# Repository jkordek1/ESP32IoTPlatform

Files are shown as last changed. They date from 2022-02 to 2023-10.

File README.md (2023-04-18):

# ESP32IoTPlatform


[]()



## What is it?
ESP32IoTPlatform is an open source platform aimed towards students at Zagreb University of Applied Sciences who will take the IoT course.
It enables quick and easy firmware development thanks to built in sensors, actuators and other electronic components.

## Features
- Based on dual-core ESP32 microcontroller module
- External battery connector
- Battery charging via microUSB cable
- Buzzer for audio queues
- HC-SR04 ultrasonic sensor connector
- MOSFET output
- Relay output
- LDR
- Potentiometer
- 1.3" OLED screen
- microSD slot
- accelerometer & gyro
- BME280 temperature and humidity sensor
- GPS module
- WS2812-B RGB LEDs
- Touchad
- Joypad

## Images
<p align="center">
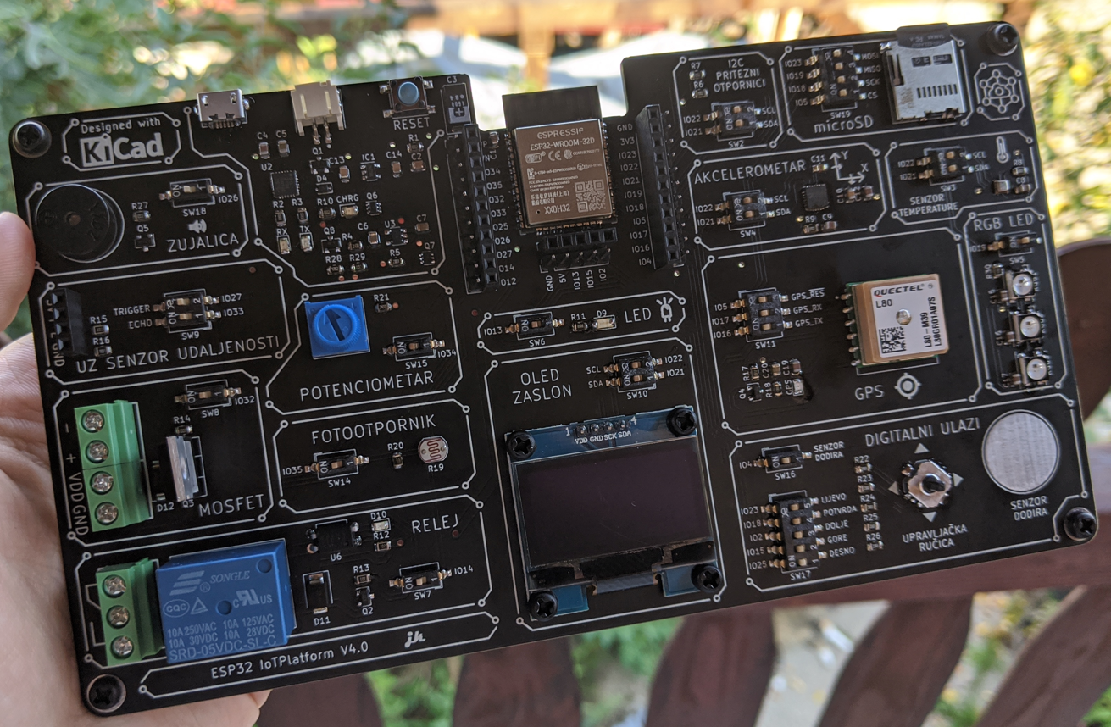
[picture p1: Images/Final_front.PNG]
 
</p>

## Project folder structure
    .
    ├── ...
    ├── Images                  # Images of the project
    ├── Output files            # Gerber files
    ├── KiCadFiles              # Main folder
    │   ├── 3d modeli           # 3D models of added components
    │   ├── Board2Pdf           # Assembly files
    │   ├── bom                 # ibom assembly files
    │   └── gerber              # gerber
    ├── Schematic.pdf           # Schematic .pdf file
    └── ...

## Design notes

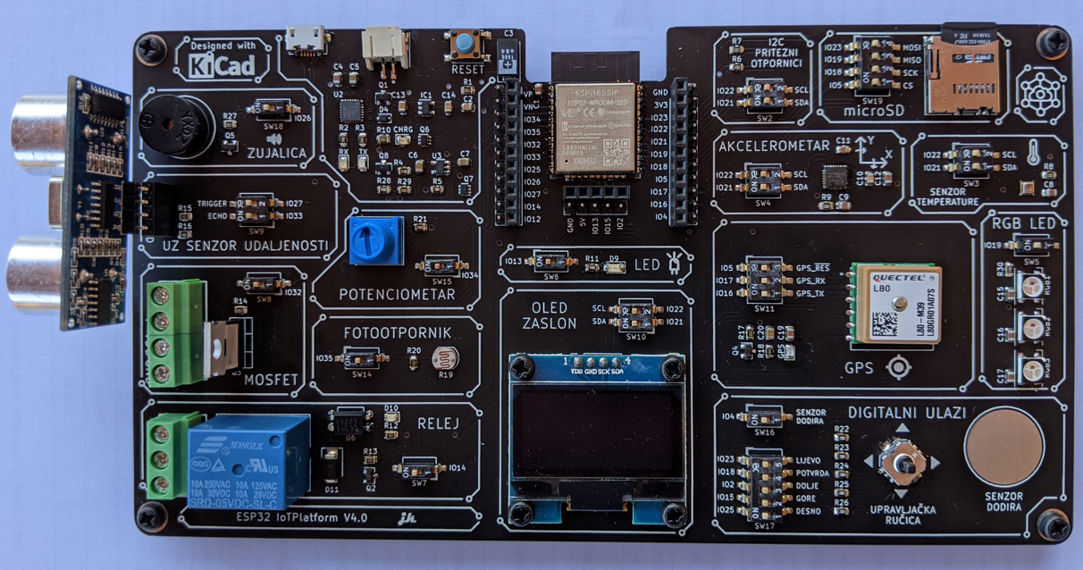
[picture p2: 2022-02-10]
Images/Front_2.PNG

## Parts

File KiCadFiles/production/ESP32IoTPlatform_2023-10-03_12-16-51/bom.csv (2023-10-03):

Designator | Footprint | Quantity | Value | LCSC Part #
BZ1 | PS1240P02BT | 1 | Buzzer
C1, C12, C15, C16, C17, C19, C4, C8, C9 | 0805 | 9 | 100n/50V
C10 | 0805 | 1 | 10n/6.3V
C11 | 0805 | 1 | 2200p/50V
C13, C14, C2 | 0805 | 3 | 1u/50V
C20, C5, C6, C7 | 0805 | 4 | 10u/16V
C3 | CP_EIA-7343-31_Kemet-D | 1 | 1500u
D1, D13 | 0805 | 2 | Green
D10, D2 | 0805 | 2 | Red
D11, D12 | D_SMA | 2 | S1BB-13-F
D3 | 0805 | 1 | Orange
D4 | D_SOD-323 | 1 | B5819WS
D5, D6, D7 | LED_WS2812B_PLCC4_5.0x5.0mm_P3.2mm | 3 | WS2812B
D9 | 1206 | 1 | Blue
H1, H2, H3, H4 | MountingHole_3.2mm_M3_Pad_Via_edited | 4 | MountingHole
IC1 | SOT-23-5 | 1 | ME6211C33M5G
J1 | USB_Micro-AB_Molex_47590-0001 | 1 | USB_B_Micro
J10, J9 | PinSocket_1x11_P2.54mm_Vertical | 2 | Conn_01x11_Female
J11, J12 | PinHeader_1x11_P2.54mm_Vertical | 2 | Conn_01x11_Male
J2 | TerminalBlock_Phoenix_MKDS-1,5-3-5.08_1x03_P5.08mm_Horizontal | 1 | Screw_Terminal_01x03
J3, J4 | TerminalBlock_Phoenix_MKDS-1,5-2-5.08_1x02_P5.08mm_Horizontal | 2 | Screw_Terminal_01x02
J5 | PinSocket_1x04_P2.54mm_Vertical | 1 | Conn_01x04_Female
J6 | OLED | 1 | OLED
J7 | PinSocket_1x05_P2.54mm_Vertical | 1 | Conn_01x05_Female
J8 | PinHeader_1x05_P2.54mm_Vertical | 1 | Conn_01x05_Male
JST1 | A2001WR-S-2P_JST2.0 | 1 | JST2.0
K1 | Relay_SPDT_SANYOU_SRD_Series_Form_C | 1 | SANYOU_SRD_Form_C
Q1, Q8 | SOT-23 | 2 | CJ2301
Q2 | SOT-23 | 1 | S8050G
Q3 | TO-220-3_Vertical | 1 | IRLZ44N
Q4, Q5 | SOT-23 | 2 | SI2302DS
Q6 | SOT-363_SC-70-6 | 1 | Q_DUAL_NPN_UMH3N
Q7 | SOT-363_SC-70-6 | 1 | Q_DUAL_PNP_BCM857BS
R1, R10, R14, R17, R20, R27, R29, R6, R7, R8, R9 | 0805 | 11 | 10k
R11, R2, R3, R31, R32 | 0805 | 5 | 330
R12, R13, R15 | 0805 | 3 | 1k
R16 | 0805 | 1 | 1k5
R18, R30 | 0805 | 2 | 470
R19 | R_LDR_7x6mm_P5.1mm_Vertical | 1 | LDR
R21, R4 | 0805 | 2 | 243
R22, R23, R24, R25, R26, R5 | 0805 | 6 | 2k
R28 | 0805 | 1 | 47k
RV1 | Potentiometer_Bourns_3386P_Vertical | 1 | 10k
SD1 | MOLEX_47352-1001 | 1 | microSD-MOLEX-473521001
SW1 | SW_SPST_PTS645 | 1 | SW_Push
SW10, SW2, SW3, SW4, SW9 | SW_DIP_SPSTx02_Slide_6.7x6.64mm_W6.73mm_P2.54mm_LowProfile_JPin | 5 | SW_x02
SW11 | SW_DIP_SPSTx03_Slide_6.7x9.18mm_W6.73mm_P2.54mm_LowProfile_JPin | 1 | SW_x03
SW14, SW15, SW16, SW18, SW5, SW6, SW7, SW8 | SW_DIP_SPSTx01_Slide_6.7x4.1mm_W6.73mm_P2.54mm_LowProfile_JPin | 8 | SW_x01
SW17 | SW_DIP_SPSTx05_Slide_6.7x14.26mm_W6.73mm_P2.54mm_LowProfile_JPin | 1 | SW_x05
SW19 | SW_DIP_SPSTx04_Slide_6.7x11.72mm_W6.73mm_P2.54mm_LowProfile_JPin | 1 | SW_x04
T1 | Alps_SKRHABE010 | 1 | SKRHABE010
TP1 | Touchpad | 1 | Touchpad
U1 | ESP32-WROOM-32 | 1 | ESP32-WROOM-32D
U2 | QFN-24-1EP_4x4mm_P0.5mm_EP2.6x2.6mm | 1 | CP2104
U3 | TSOT-23-5 | 1 | TP4054
U4 | Bosch_LGA-8_2.5x2.5mm_P0.65mm_ClockwisePinNumbering | 1 | BME280
U5 | InvenSense_QFN-24_4x4mm_P0.5mm | 1 | MPU-6050
U6 | DIP-4_W7.62mm | 1 | PC817
U7 | L80-M39 | 1 | L80-M39

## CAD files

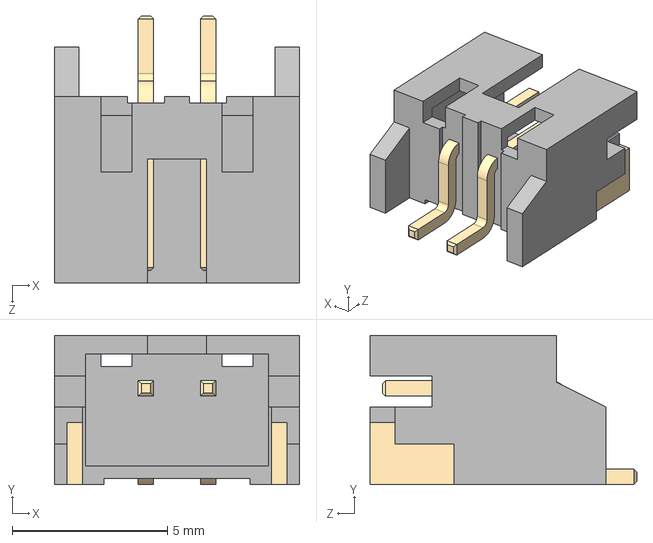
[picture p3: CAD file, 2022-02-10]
KiCadFiles/3d modeli/S2B-PH-SM4-TB.STEP
7.90 x 4.80 x 8.60 mm

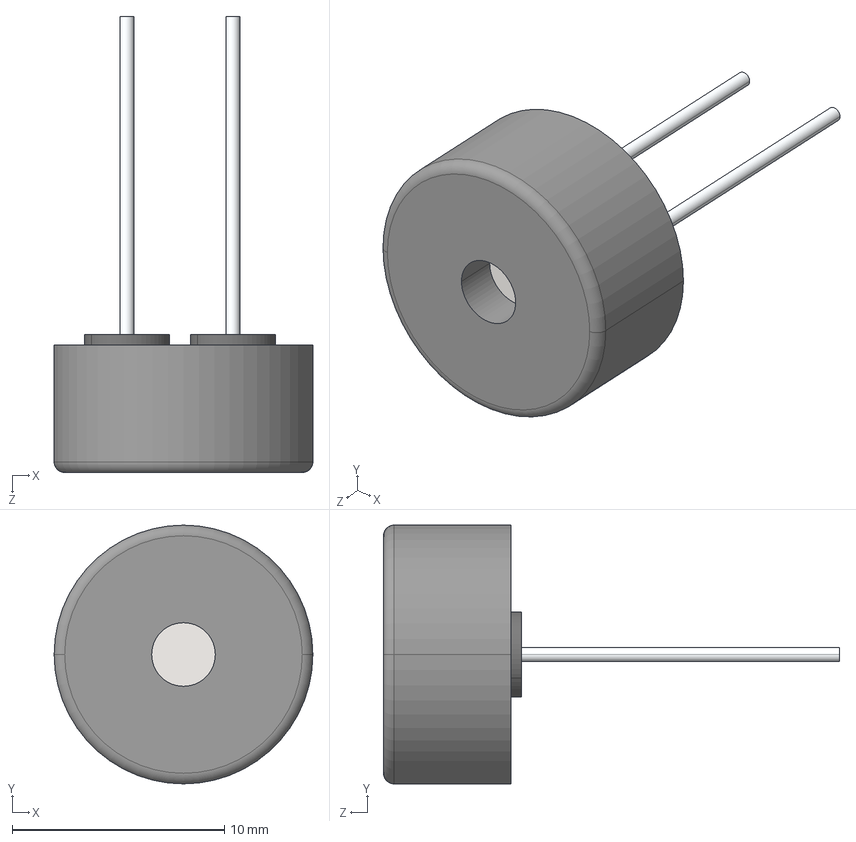
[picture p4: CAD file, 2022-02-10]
KiCadFiles/3d modeli/PS1240P02BT.step
12.2 x 12.2 x 21.5 mm
leg x 2
legbase x 2

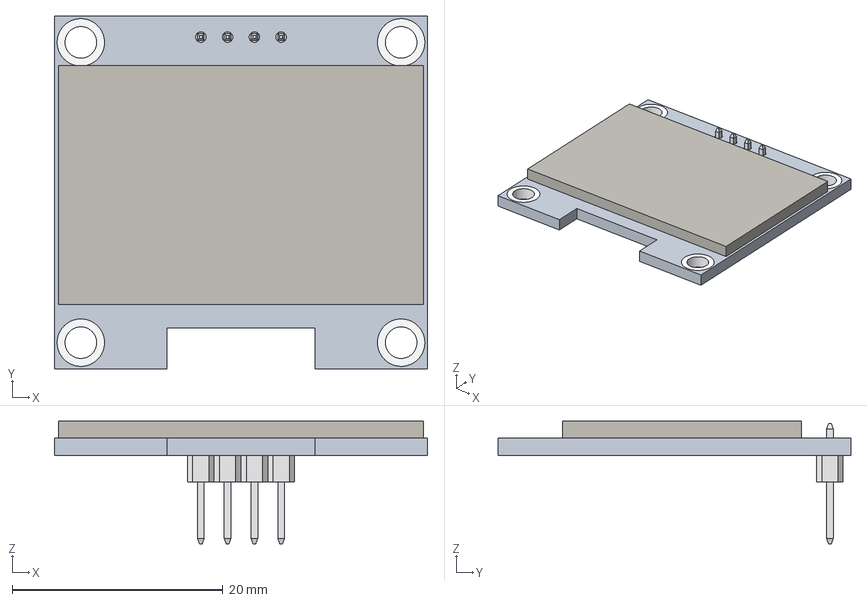
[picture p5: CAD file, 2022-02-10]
KiCadFiles/3d modeli/Geekcreit 1.3 Inch 4Pin.step
35.4 x 33.5 x 11.6 mm
2.54mm_pin_header x 4

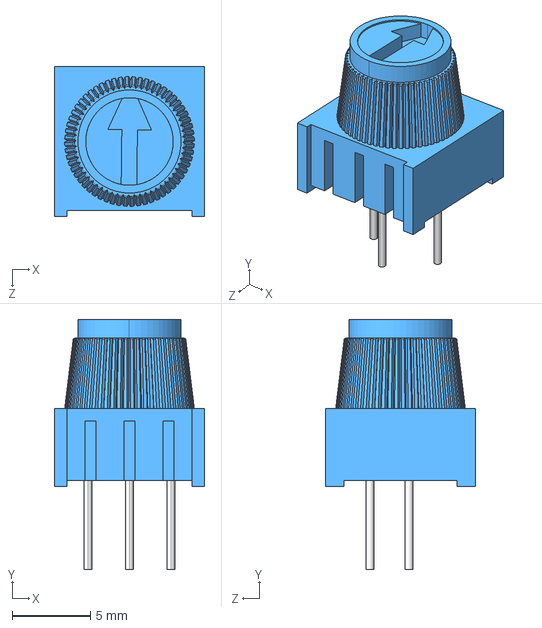
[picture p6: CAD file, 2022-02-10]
KiCadFiles/3d modeli/10 KILO-OHM BREADBOARD TRIM POTENTIOMETER WITH KNOB.STEP
9.60 x 16.0 x 9.60 mm
BASE, 10 KILO-OHM BREADBOARD TRIM POTENTIOMETER WITH KNOB
KNOB, 10 KILO-OHM BREADBOARD TRIM POTENTIOMETER WITH KNOB

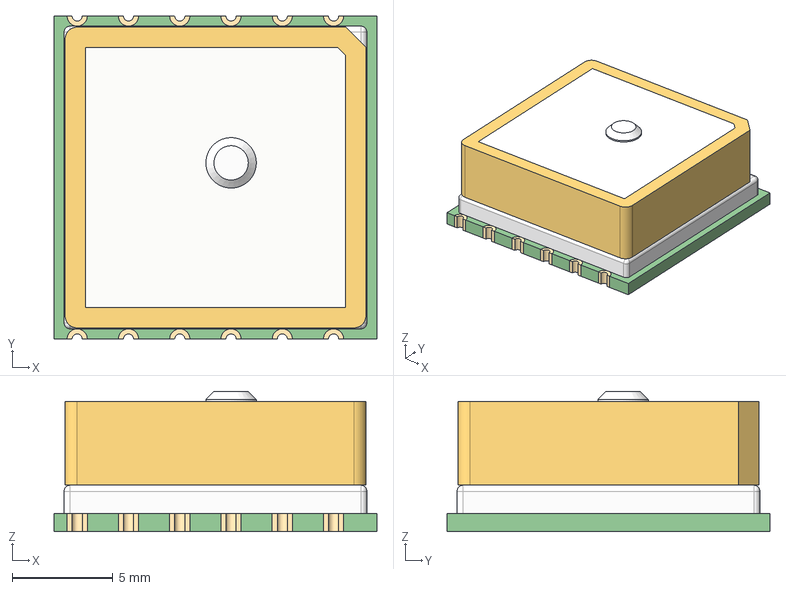
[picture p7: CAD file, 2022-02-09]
KiCadFiles/3d modeli/Quectel L80.step
16.0 x 16.0 x 6.95 mm

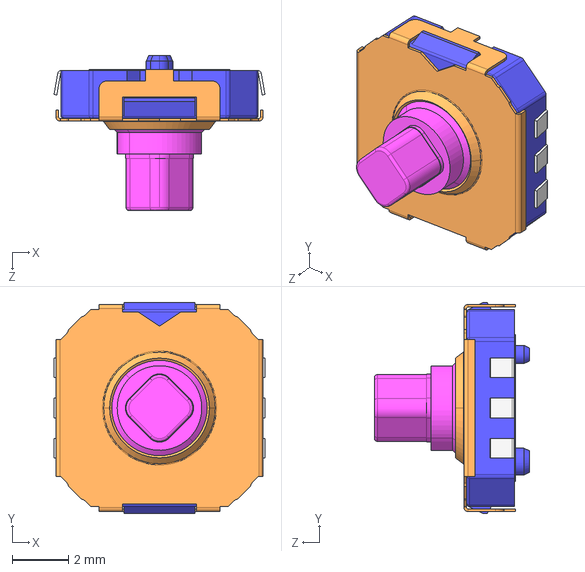
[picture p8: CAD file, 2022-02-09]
KiCadFiles/3d modeli/SKRHAB.STEP
7.48 x 7.50 x 5.50 mm

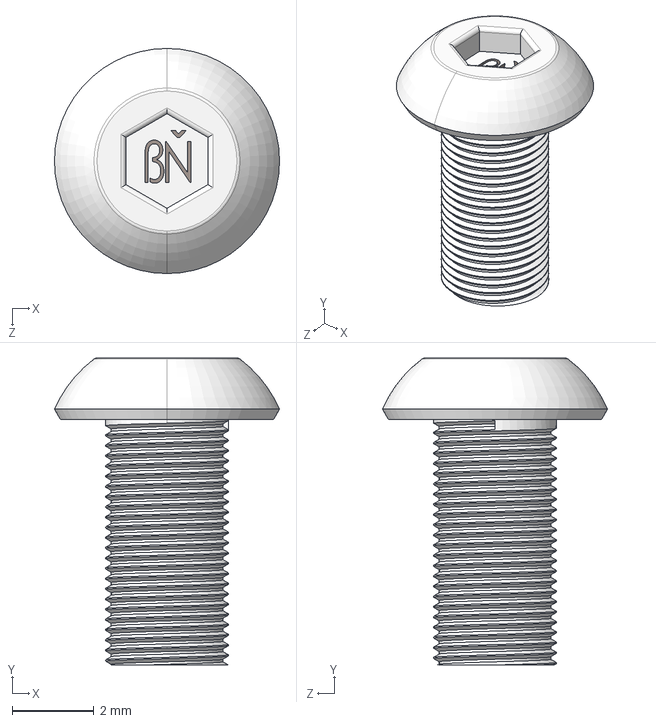
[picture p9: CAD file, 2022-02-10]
KiCadFiles/3d modeli/Screw_Machine_M3x6.STEP
5.50 x 7.50 x 5.50 mm

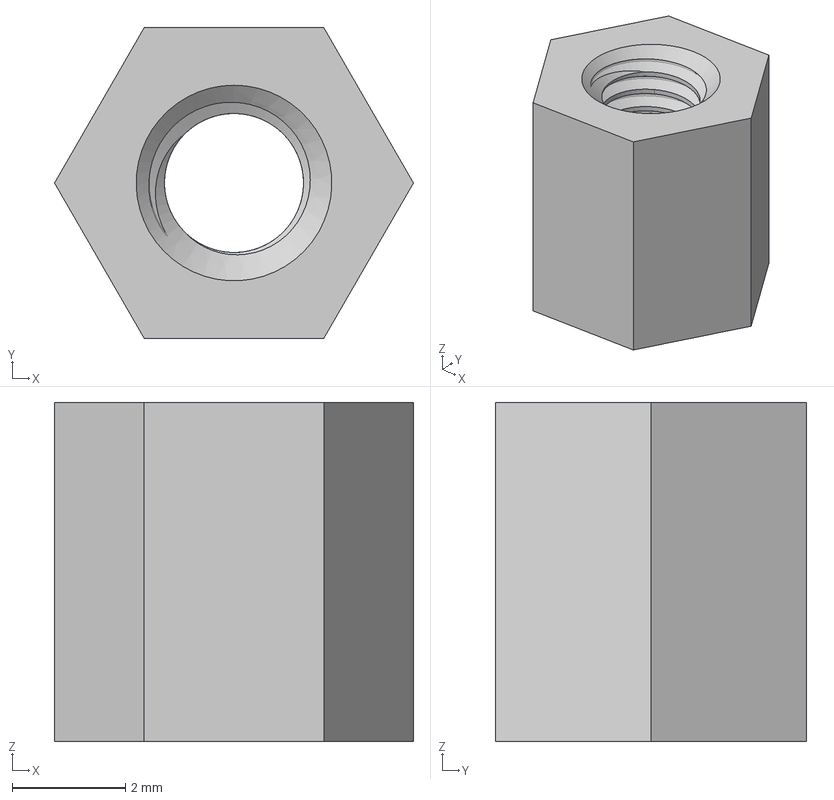
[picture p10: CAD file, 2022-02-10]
KiCadFiles/3d modeli/hex spacer standoff nut_M3 L6.stp
6.35 x 5.50 x 6.00 mm

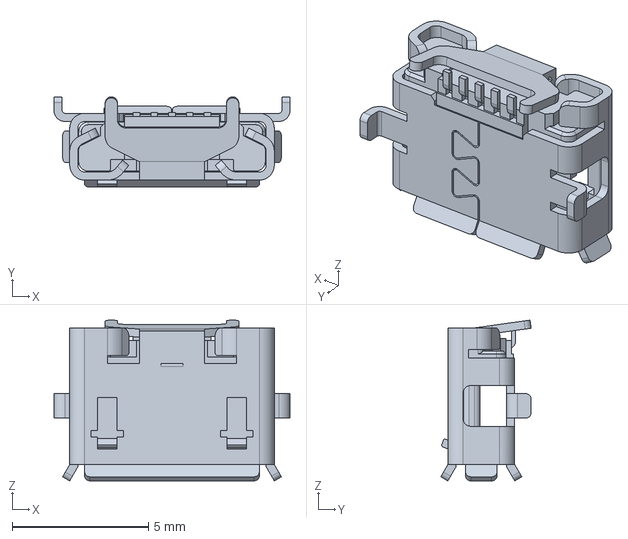
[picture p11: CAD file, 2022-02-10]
KiCadFiles/3d modeli/475890001.stp
8.65 x 3.31 x 5.89 mm

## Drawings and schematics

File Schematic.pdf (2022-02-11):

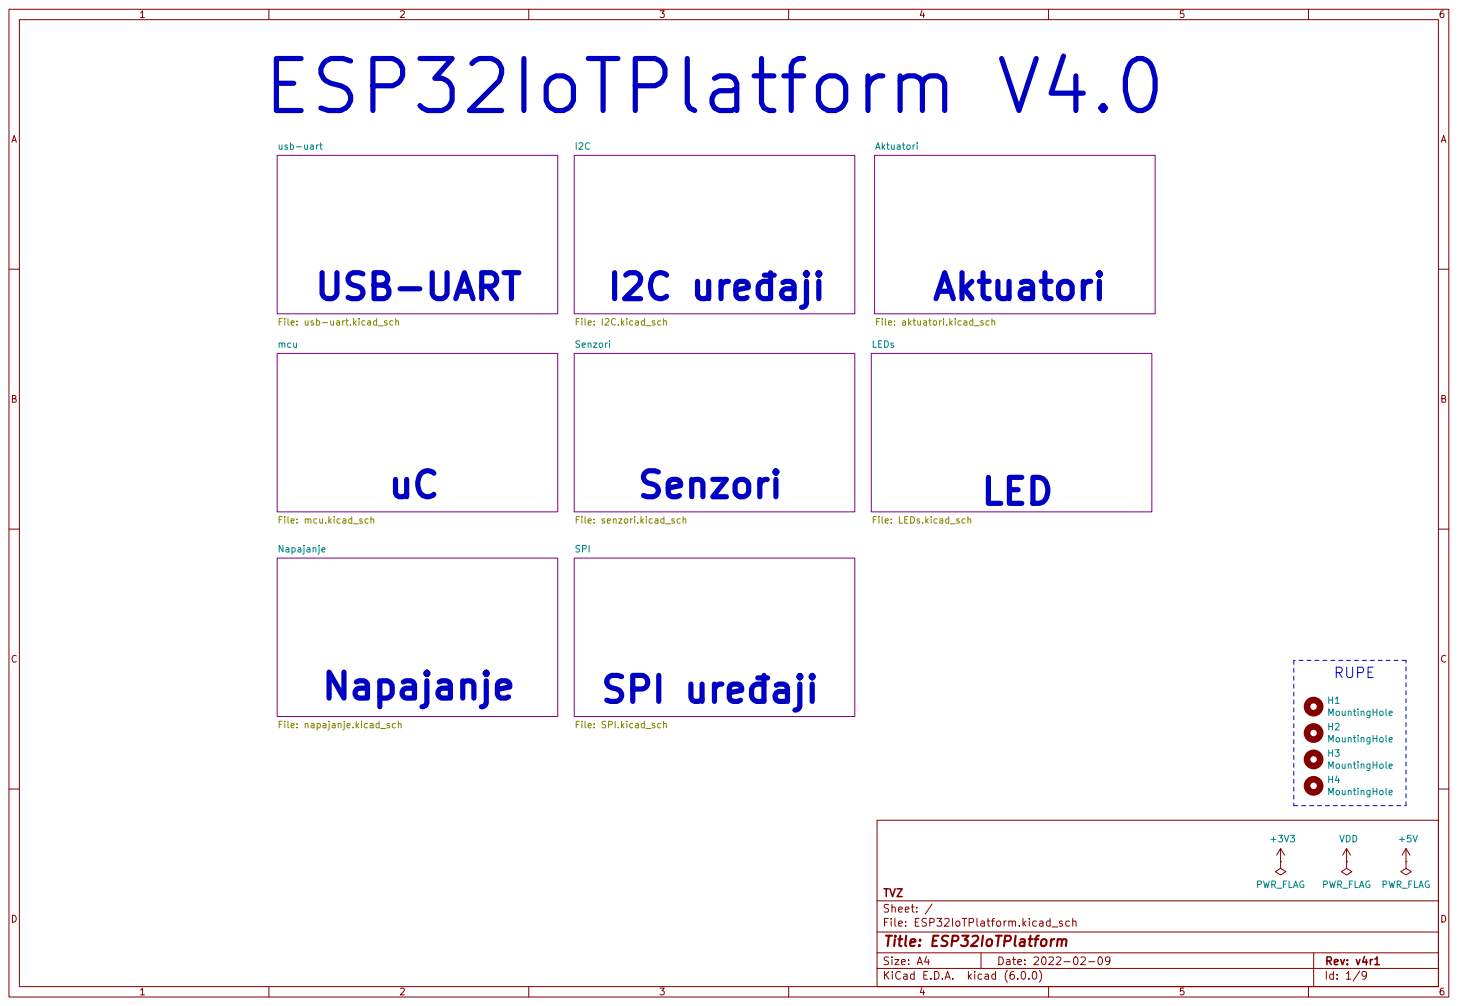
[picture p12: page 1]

ESP32IoTPlatform V4.0
usb-uart File: usb-uart.kicad_sch Napajanje

LEDs File: LEDs.kicad_sch Aktuatori File: aktuatori.kicad_sch

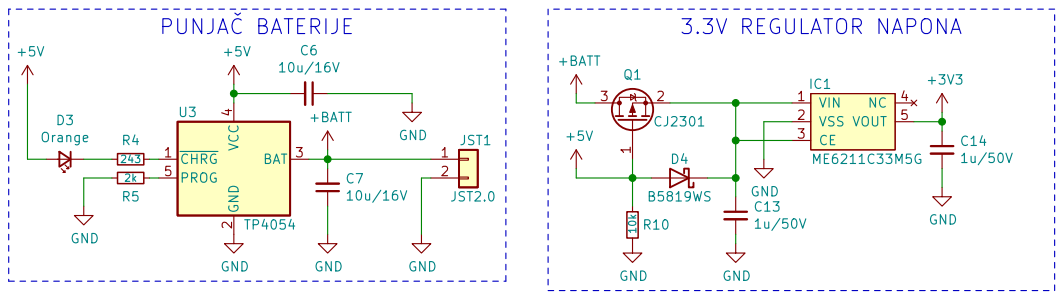
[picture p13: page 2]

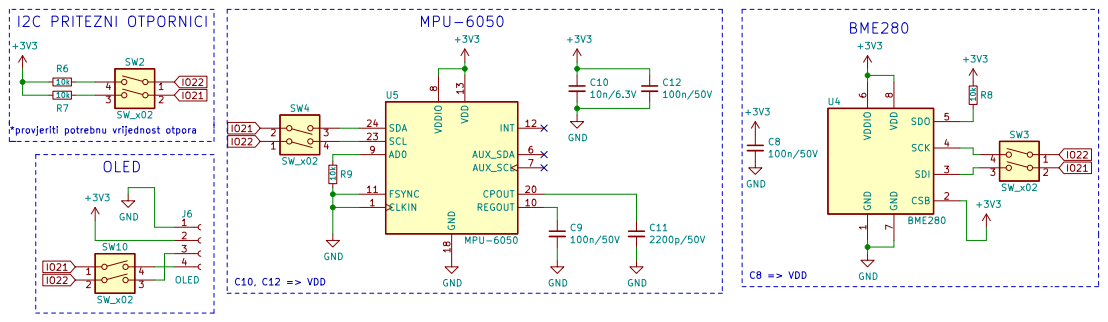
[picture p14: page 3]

1 CSB 2 SDI 3 SCK 4 SDO 5 VDDIO

*provjeriti potrebnu vrijednost otpora

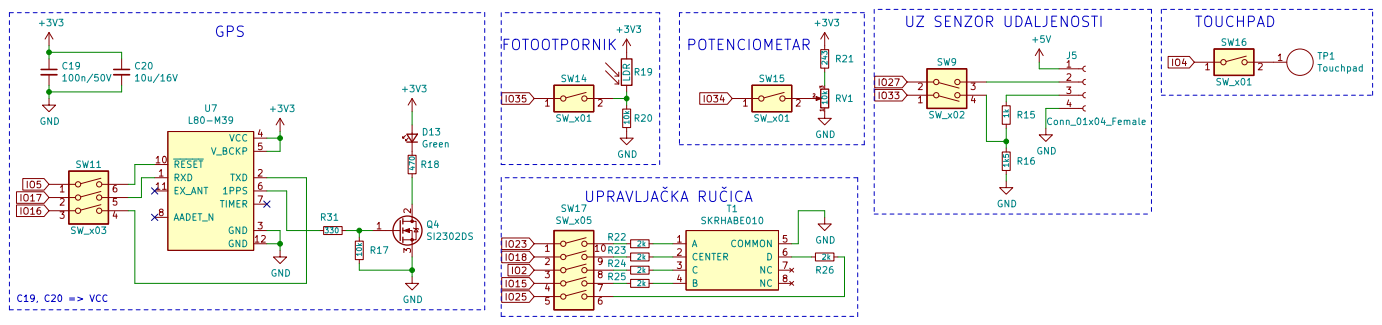
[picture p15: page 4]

File: senzori.kicad_sch Sheet: /Senzori/ TVZ

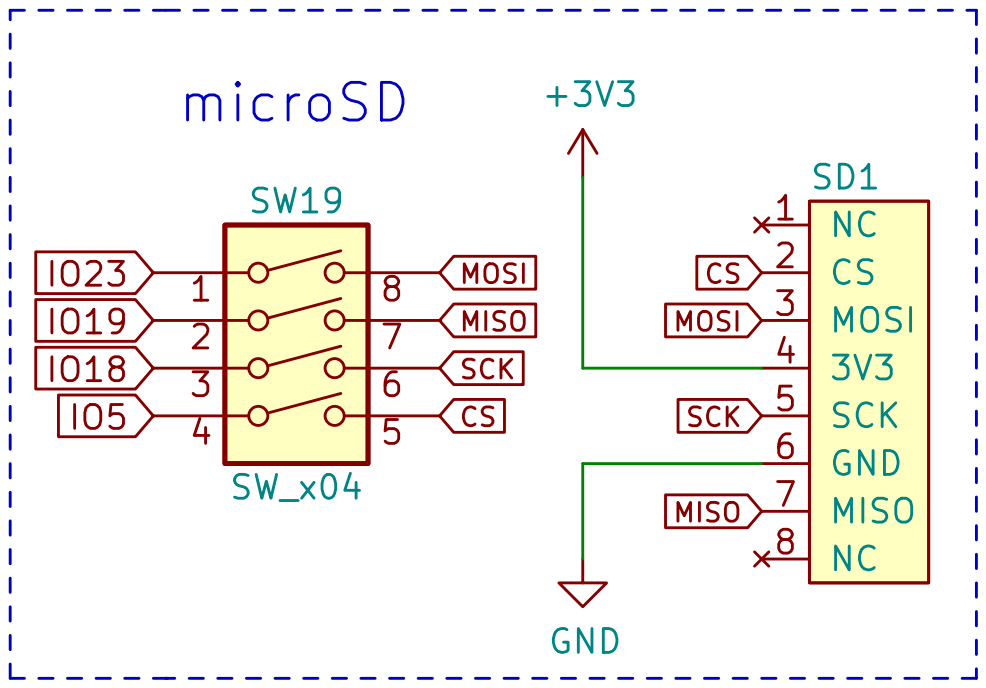
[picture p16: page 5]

CSMOSI SCK microSD
File: SPI.kicad_sch Sheet: /SPI/ TVZ GND

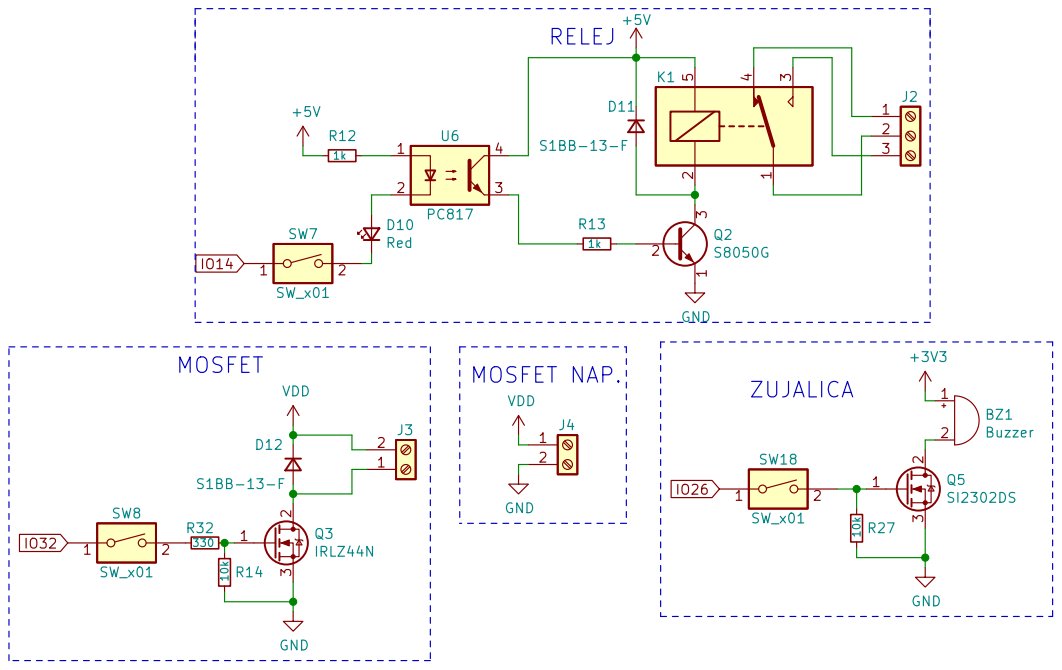
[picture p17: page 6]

File: aktuatori.kicad_sch Sheet: /Aktuatori/ TVZ

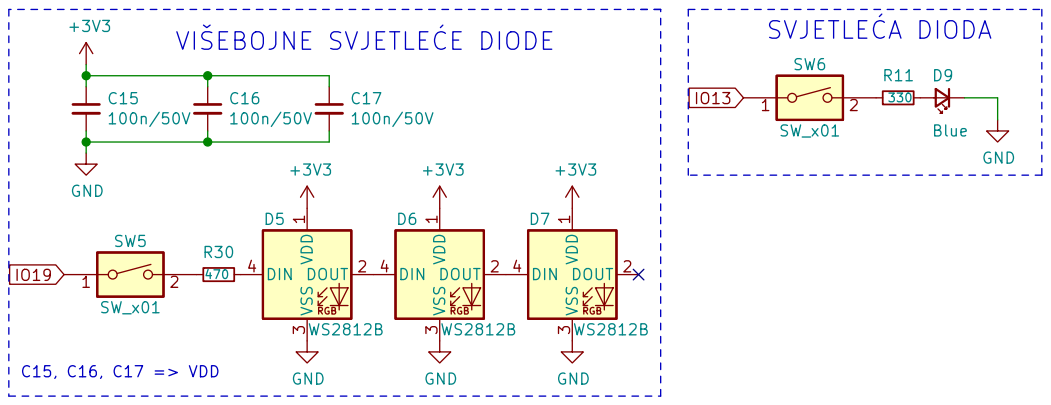
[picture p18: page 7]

File: LEDs.kicad_sch Sheet: /LEDs/ TVZ

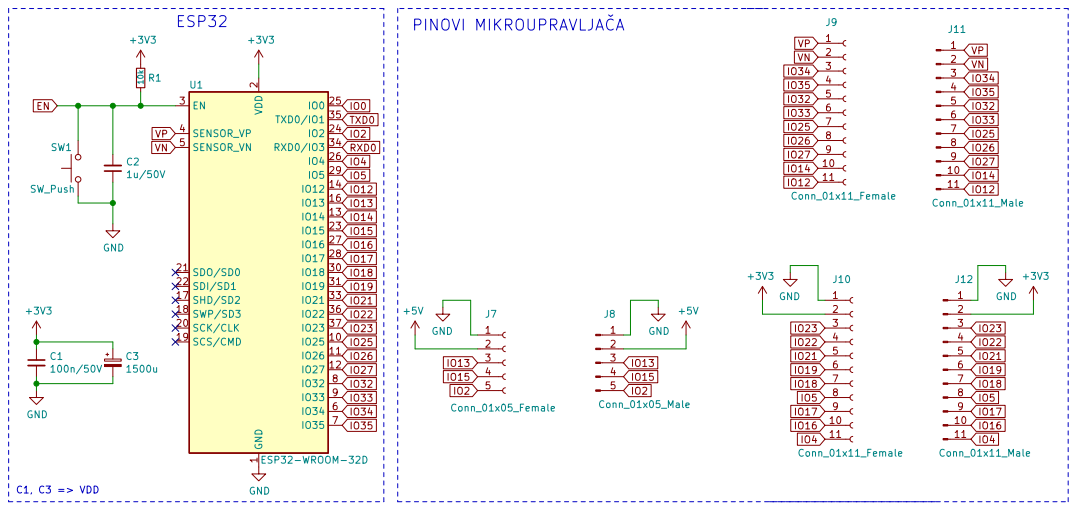
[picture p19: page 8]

2 SCK/CLK 20 SDO/SD0 21 SDI/SD1 22

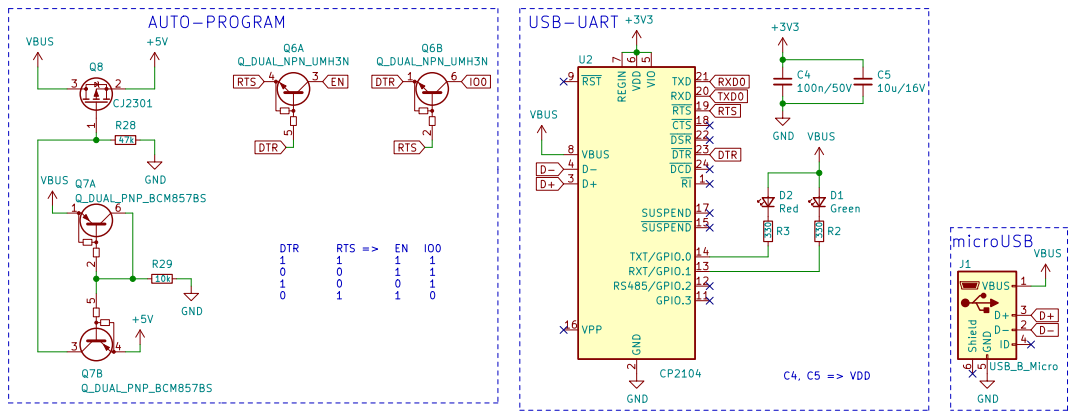
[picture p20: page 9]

2 RXD 20 TXD 21 ~{DSR}22 ~{DTR}23 ~{DCD}24 D+ 3 D- 4 VIO

File: usb-uart.kicad_sch Sheet: /usb-uart/ TVZ

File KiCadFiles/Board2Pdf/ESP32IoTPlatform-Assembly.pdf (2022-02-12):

1 | 2 | 3 | 4 | 5 | 6

A

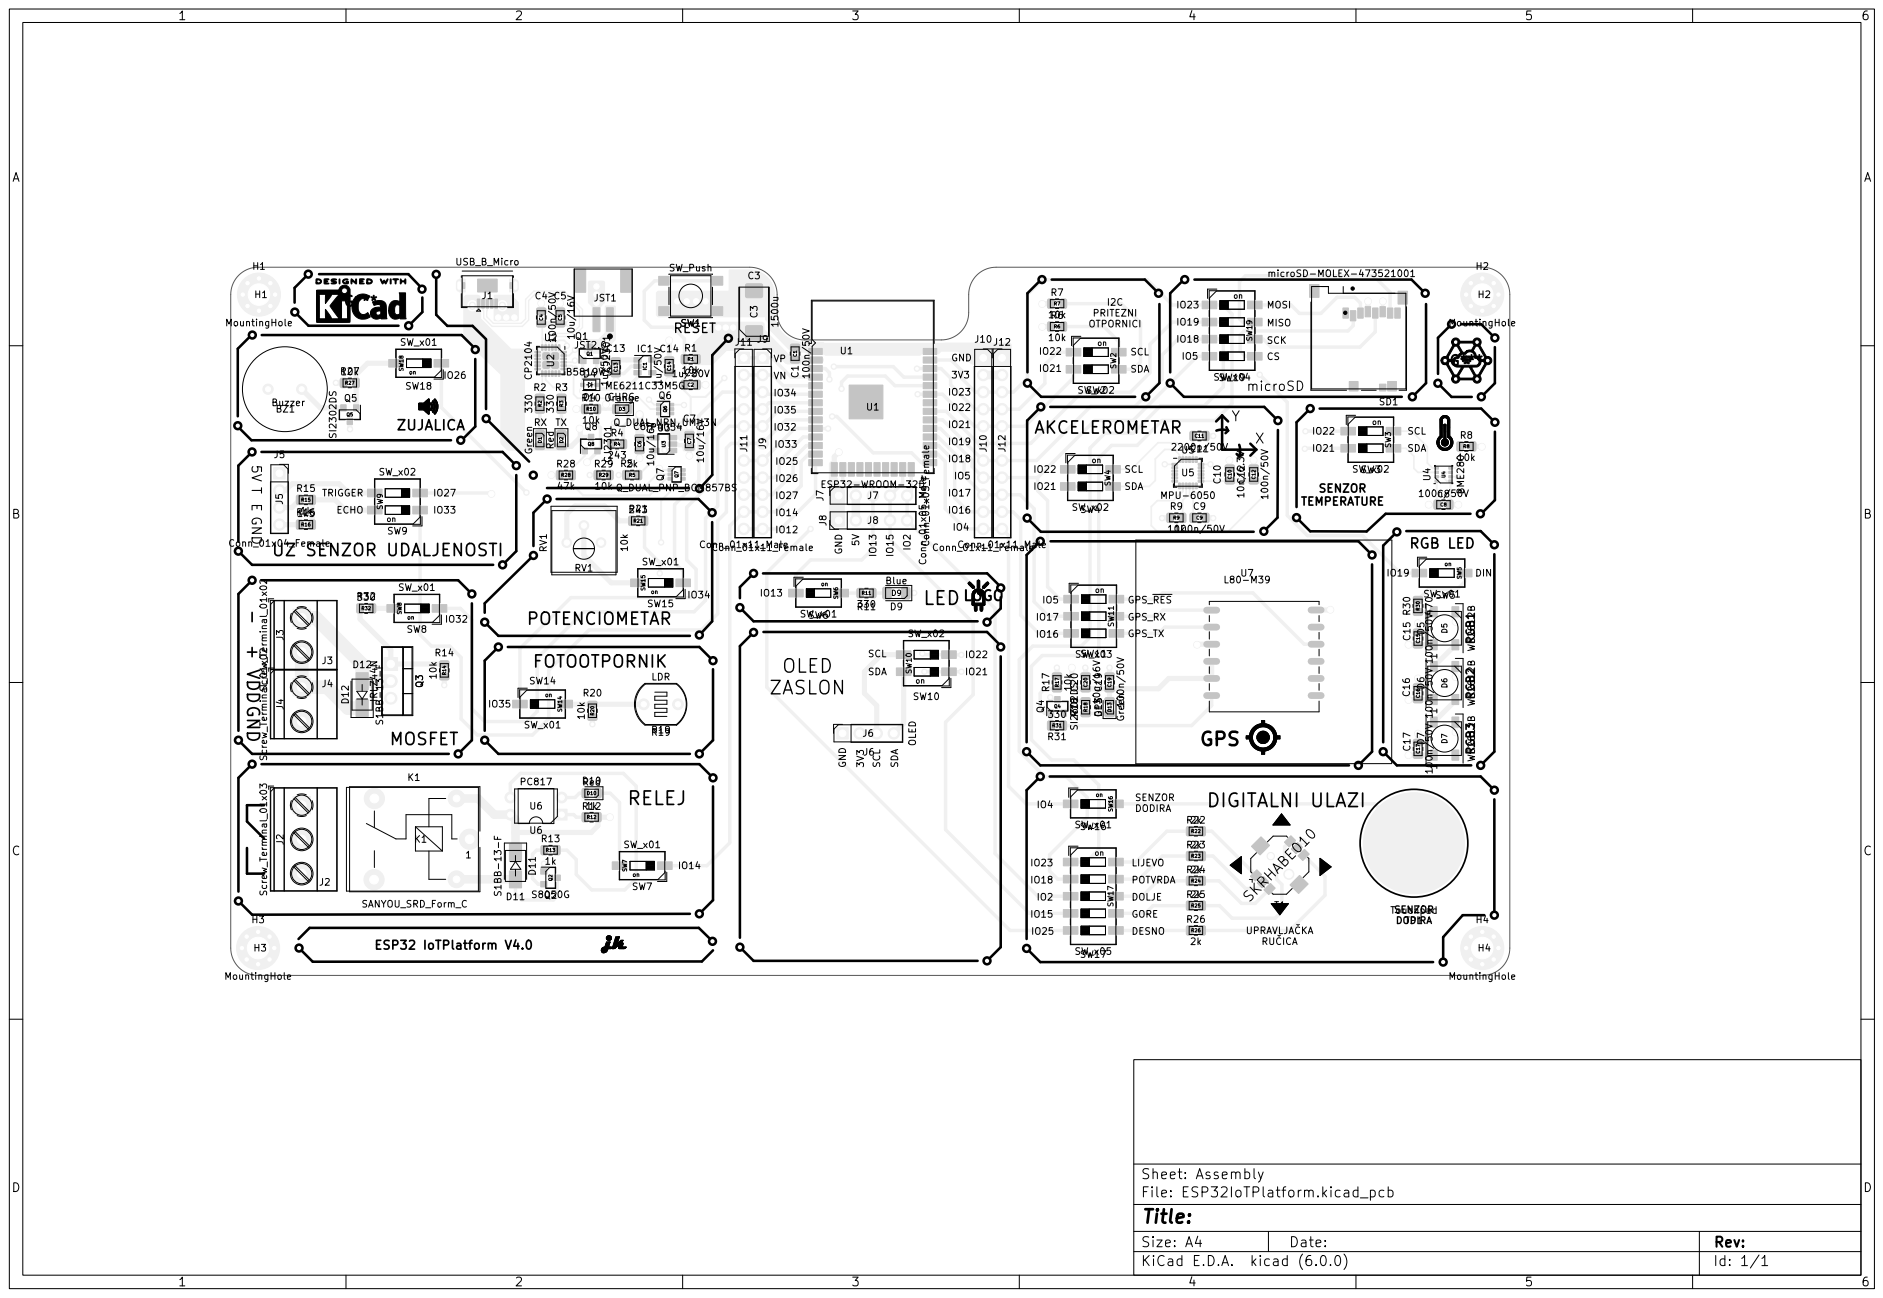
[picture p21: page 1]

SCL
SDA
TEMPERATURE DIGITALNI ULAZI POTVRDA

1 | 2 | 3 | 4 | 5 | 6

A

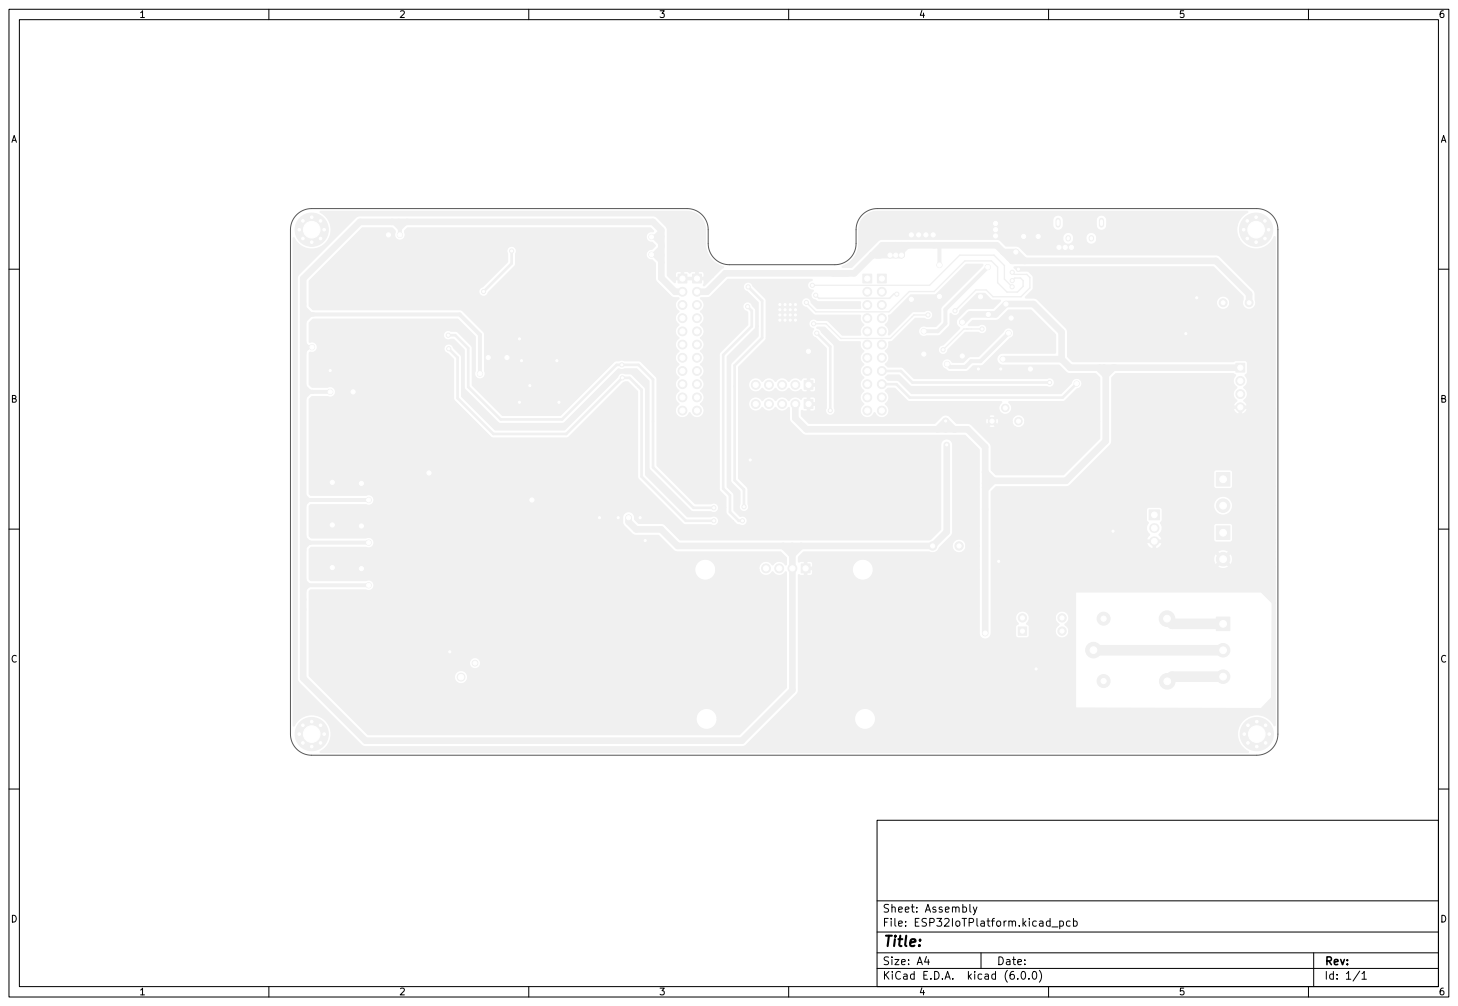
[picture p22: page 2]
D Date: KiCad E.D.A. kicad (6.0.0) Size: A4; Rev:; Id: 1/1 Title:; File: ESP32IoTPlatform.kicad_pcb; Sheet: Assembly

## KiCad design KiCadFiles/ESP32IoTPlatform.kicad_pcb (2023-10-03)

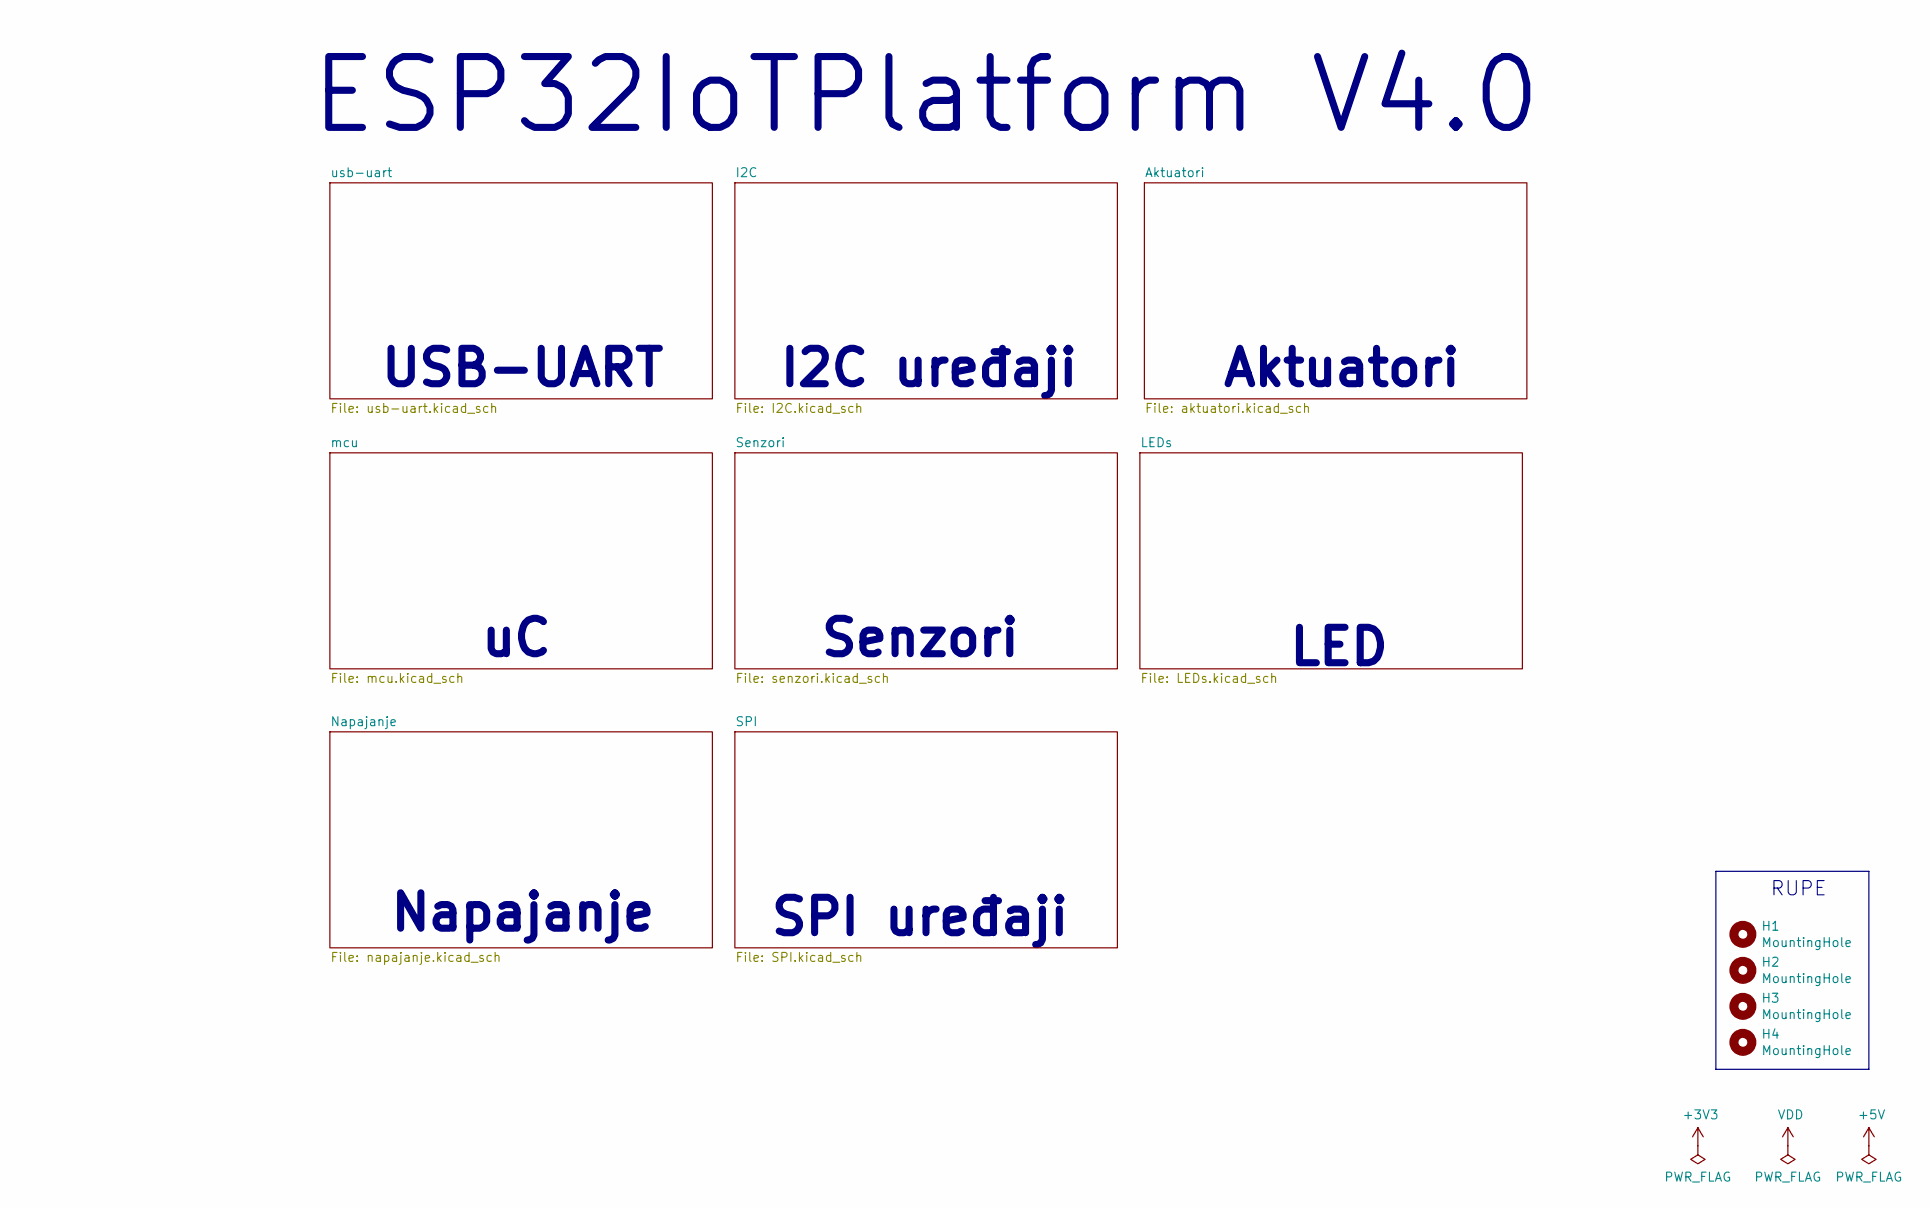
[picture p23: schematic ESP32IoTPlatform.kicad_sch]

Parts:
H1, H2, H3, H4: MountingHole; MountingHole_3.2mm_M3_Pad_Via_edited

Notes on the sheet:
RUPE
LED
Aktuatori
Senzori
Napajanje
SPI uređaji
ESP32IoTPlatform V4.0
I2C uređaji
USB-UART

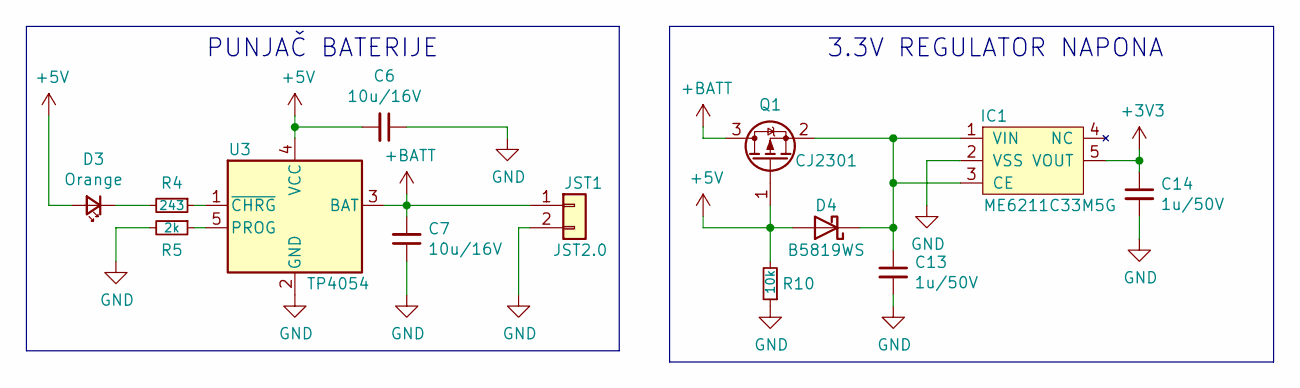
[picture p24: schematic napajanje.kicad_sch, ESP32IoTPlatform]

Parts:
C6, C7: 10u/16V; C_0805_2012Metric
C13, C14: 1u/50V; C_0805_2012Metric
D3: Orange; LED_0805_2012Metric
D4: B5819WS; D_SOD-323
IC1: ME6211C33M5G; SOT-23-5
JST1: JST2.0; A2001WR-S-2P_JST2.0
Q1: CJ2301; SOT-23
R4: 243; R_0805_2012Metric
R5: 2k; R_0805_2012Metric
R10: 10k; R_0805_2012Metric
U3: TP4054; TSOT-23-5

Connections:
+3V3: C14.1, IC1.5 (VOUT); also elsewhere on the board
+5V: C6.2, D3.2 (A), D4.2 (A), Q1.1 (G), R10.2, U3.4 (VCC); also elsewhere on the board
+BATT: C7.2, JST1.1, Q1.3 (D), U3.3 (BAT)
GND: C6.1, C7.1, C13.2, C14.2, IC1.2 (VSS), JST1.2, R5.2, R10.1, U3.2 (GND); also elsewhere on the board
unnamed: C13.1, D4.1 (K), IC1.1 (VIN), IC1.3 (CE), Q1.2 (S)
unnamed: D3.1 (K), R4.2
unnamed: R4.1, U3.1 (~CHRG)
unnamed: R5.1, U3.5 (PROG)

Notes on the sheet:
3.3V REGULATOR NAPONA
PUNJAČ BATERIJE

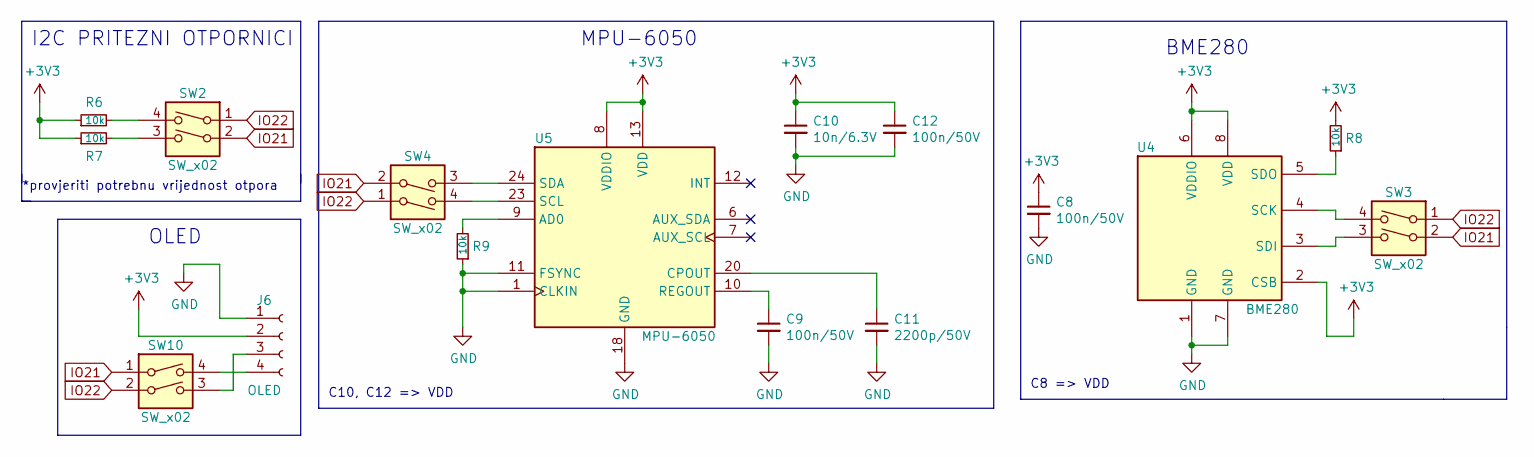
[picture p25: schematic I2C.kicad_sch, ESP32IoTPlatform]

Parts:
C8, C9, C12: 100n/50V; C_0805_2012Metric
C10: 10n/6.3V; C_0805_2012Metric
C11: 2200p/50V; C_0805_2012Metric
J6: OLED
R6, R7, R8, R9: 10k; R_0805_2012Metric
SW2, SW3, SW4, SW10: SW_x02; SW_DIP_SPSTx02_Slide_6.7x6.64mm_W6.73mm_P2.54mm_LowProfile_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
U4: BME280; Bosch_LGA-8_2.5x2.5mm_P0.65mm_ClockwisePinNumbering
U5: MPU-6050; InvenSense_QFN-24_4x4mm_P0.5mm

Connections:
+3V3: C8.1, C10.1, C12.1, J6.2, R6.1, R7.1, R8.2, U4.2 (CSB), U4.6 (VDDIO), U4.8 (VDD), U5.8 (VDDIO), U5.13 (VDD); also elsewhere on the board
GND: C8.2, C9.2, C10.2, C11.2, C12.2, J6.1, R9.1, U4.1 (GND), U4.7 (GND), U5.1 (CLKIN), U5.11 (FSYNC), U5.18 (GND); also elsewhere on the board
IO21: SW2.2, SW3.2, SW4.2, SW10.1; also elsewhere on the board
IO22: SW2.1, SW3.1, SW4.1, SW10.2; also elsewhere on the board
unnamed: C9.1, U5.10 (REGOUT)
unnamed: C11.1, U5.20 (CPOUT)
unnamed: J6.3, SW10.3
unnamed: J6.4, SW10.4
unnamed: R6.2, SW2.4
unnamed: R7.2, SW2.3
unnamed: R8.1, U4.5 (SDO)
unnamed: R9.2, U5.9 (AD0)
unnamed: SW3.3, U4.3 (SDI)
unnamed: SW3.4, U4.4 (SCK)
unnamed: SW4.3, U5.24 (SDA)
unnamed: SW4.4, U5.23 (SCL)

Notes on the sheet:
BME280
*provjeriti potrebnu vrijednost otpora
OLED
I2C PRITEZNI OTPORNICI
C8 => VDD
MPU-6050
C10, C12 => VDD

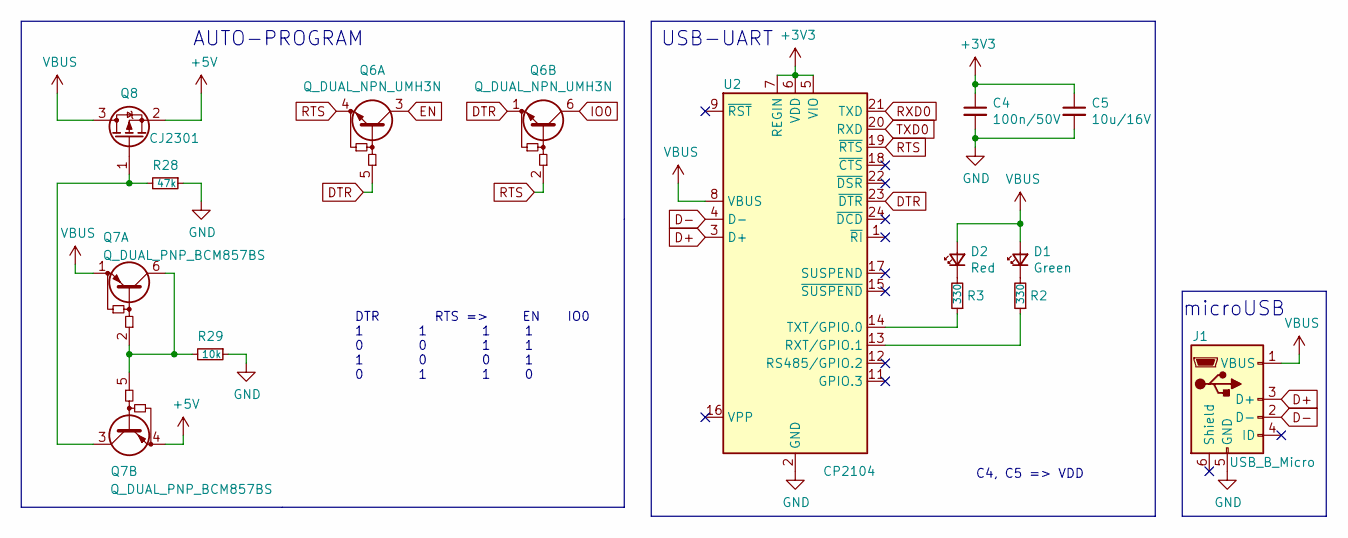
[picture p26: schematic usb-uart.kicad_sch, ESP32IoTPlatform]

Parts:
C4: 100n/50V; C_0805_2012Metric
C5: 10u/16V; C_0805_2012Metric
D1: Green; LED_0805_2012Metric
D2: Red; LED_0805_2012Metric
J1: USB_B_Micro; USB_Micro-AB_Molex_47590-0001
Q6: Q_DUAL_NPN_UMH3N; SOT-363_SC-70-6
Q7: Q_DUAL_PNP_BCM857BS; SOT-363_SC-70-6
Q8: CJ2301; SOT-23
R2, R3: 330; R_0805_2012Metric
R28: 47k; R_0805_2012Metric
R29: 10k; R_0805_2012Metric
U2: CP2104; QFN-24-1EP_4x4mm_P0.5mm_EP2.6x2.6mm

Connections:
+3V3: C4.1, C5.1, U2.5 (VIO), U2.6 (VDD), U2.7 (REGIN); also elsewhere on the board
+5V: Q7.4 (E2), Q8.2 (S); also elsewhere on the board
D+: J1.3 (D+), U2.3 (D+)
D-: J1.2 (D-), U2.4 (D-)
DTR: Q6.1 (E1), Q6.5 (B1), U2.23 (~DTR)
EN: Q6.3 (C1); also elsewhere on the board
GND: C4.2, C5.2, J1.5 (GND), R28.1, R29.1, U2.2 (GND), U2.25 (GND); also elsewhere on the board
IO0: Q6.6 (C1); also elsewhere on the board
unnamed: D1.1 (K), R2.2
unnamed: D2.1 (K), R3.2
unnamed: Q7.2 (B1), Q7.5 (B2), Q7.6 (C1), R29.2
unnamed: Q7.3 (C2), Q8.1 (G), R28.2
unnamed: R2.1, U2.13 (RXT/GPIO.1)
unnamed: R3.1, U2.14 (TXT/GPIO.0)
RTS: Q6.2 (B1), Q6.4 (E1), U2.19 (~RTS)
RXD0: U2.21 (TXD); also elsewhere on the board
TXD0: U2.20 (RXD); also elsewhere on the board
VBUS: D1.2 (A), D2.2 (A), J1.1 (VBUS), Q7.1 (E1), Q8.3 (D), U2.8 (VBUS)

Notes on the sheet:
AUTO-PROGRAM
C4, C5 => VDD
USB-UART
DTR RTS => EN IO0 1 1 1 1 0 0 1 1 1 0 0 1 0 1 1 0
microUSB

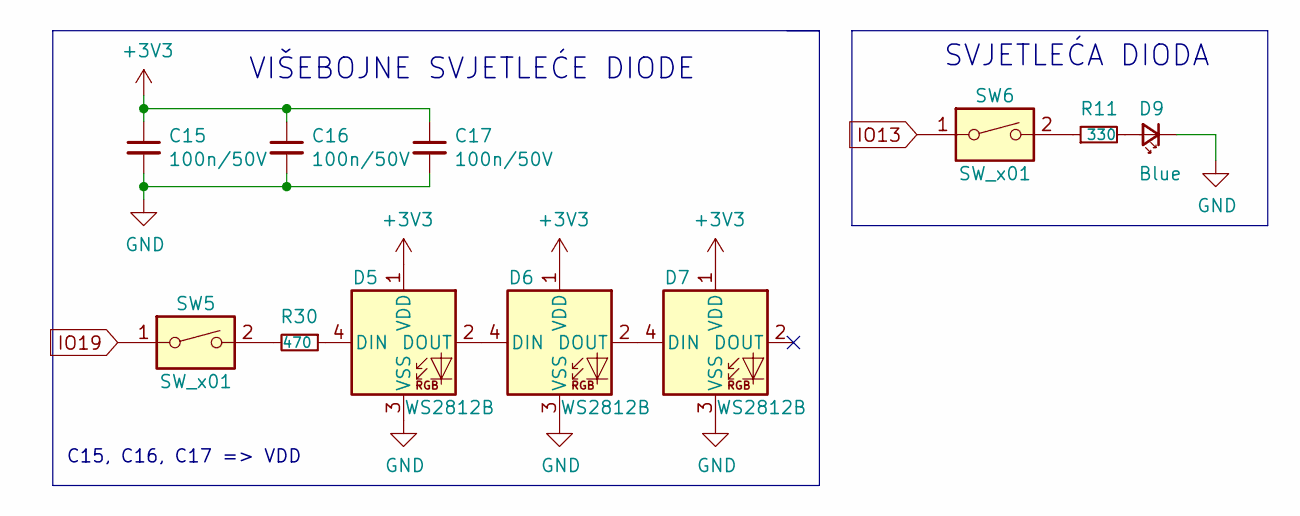
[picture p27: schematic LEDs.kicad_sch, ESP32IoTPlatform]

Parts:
C15, C16, C17: 100n/50V; C_0805_2012Metric
D5, D6, D7: WS2812B; LED_WS2812B_PLCC4_5.0x5.0mm_P3.2mm
D9: Blue; LED_1206_3216Metric
R11: 330; R_0805_2012Metric
R30: 470; R_0805_2012Metric
SW5, SW6: SW_x01; SW_DIP_SPSTx01_Slide_6.7x4.1mm_W6.73mm_P2.54mm_LowProfile_J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

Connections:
+3V3: C15.1, C16.1, C17.1, D5.1 (VDD), D6.1 (VDD), D7.1 (VDD); also elsewhere on the board
GND: C15.2, C16.2, C17.2, D5.3 (VSS), D6.3 (VSS), D7.3 (VSS), D9.1 (K); also elsewhere on the board
IO13: SW6.1; also elsewhere on the board
IO19: SW5.1; also elsewhere on the board
unnamed: D5.2 (DOUT), D6.4 (DIN)
unnamed: D5.4 (DIN), R30.1
unnamed: D6.2 (DOUT), D7.4 (DIN)
unnamed: D9.2 (A), R11.2
unnamed: R11.1, SW6.2
unnamed: R30.2, SW5.2

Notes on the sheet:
SVJETLEĆA DIODA
VIŠEBOJNE SVJETLEĆE DIODE
C15, C16, C17 => VDD

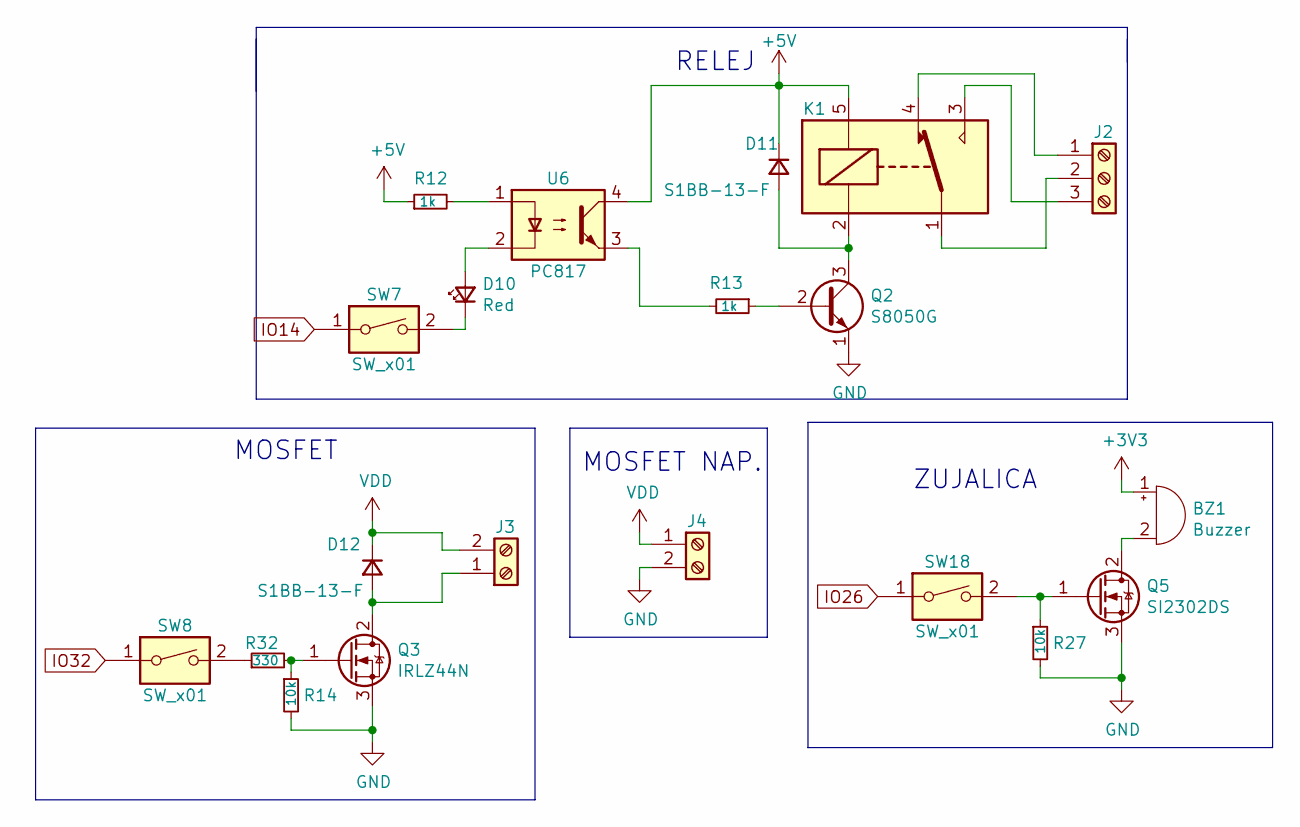
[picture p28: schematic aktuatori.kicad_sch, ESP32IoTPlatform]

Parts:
BZ1: Buzzer; PS1240P02BT
D10: Red; LED_0805_2012Metric
D11, D12: S1BB-13-F; D_SMA
J2: Screw_Terminal_01x03; TerminalBlock_Phoenix_MKDS-1,5-3-5.08_1x03_P5.08mm_Horizont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
J3, J4: Screw_Terminal_01x02; TerminalBlock_Phoenix_MKDS-1,5-2-5.08_1x02_P5.08mm_Horizont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
K1: SANYOU_SRD_Form_C; Relay_SPDT_SANYOU_SRD_Series_Form_C
Q2: S8050G; SOT-23
Q3: IRLZ44N; TO-220-3_Vertical
Q5: SI2302DS; SOT-23
R12, R13: 1k; R_0805_2012Metric
R14, R27: 10k; R_0805_2012Metric
R32: 330; R_0805_2012Metric
SW7, SW8, SW18: SW_x01; SW_DIP_SPSTx01_Slide_6.7x4.1mm_W6.73mm_P2.54mm_LowProfile_J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
U6: PC817; DIP-4_W7.62mm

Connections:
+3V3: BZ1.1 (-); also elsewhere on the board
+5V: D11.1 (K), K1.5, R12.1, U6.4; also elsewhere on the board
GND: J4.2, Q2.1 (E), Q3.3 (S), Q5.3 (S), R14.2, R27.2; also elsewhere on the board
IO14: SW7.1; also elsewhere on the board
IO26: SW18.1; also elsewhere on the board
IO32: SW8.1; also elsewhere on the board
unnamed: BZ1.2 (+), Q5.2 (D)
unnamed: D10.1 (K), SW7.2
unnamed: D10.2 (A), U6.2
unnamed: D11.2 (A), K1.2, Q2.3 (C)
unnamed: D12.2 (A), J3.1, Q3.2 (D)
unnamed: J2.1, K1.4
unnamed: J2.2, K1.1
unnamed: J2.3, K1.3
unnamed: Q2.2 (B), R13.1
unnamed: Q3.1 (G), R14.1, R32.2
unnamed: Q5.1 (G), R27.1, SW18.2
unnamed: R12.2, U6.1
unnamed: R13.2, U6.3
unnamed: R32.1, SW8.2
VDD: D12.1 (K), J3.2, J4.1

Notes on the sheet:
ZUJALICA
MOSFET NAP.
RELEJ
MOSFET

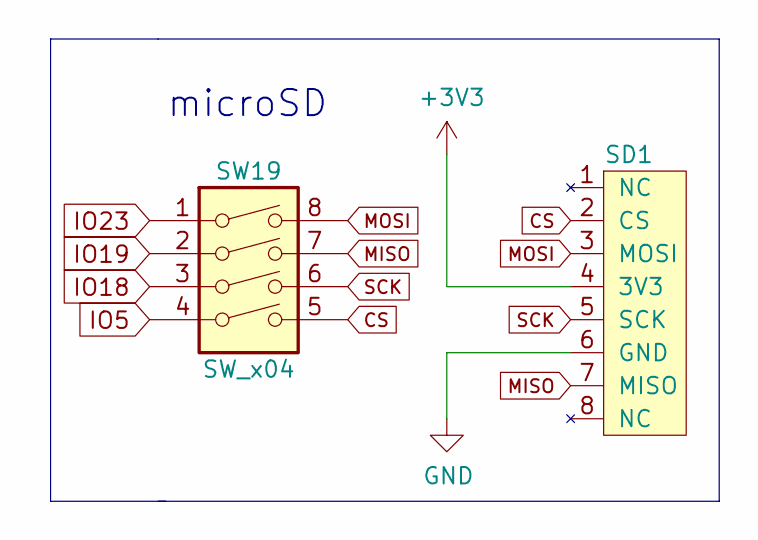
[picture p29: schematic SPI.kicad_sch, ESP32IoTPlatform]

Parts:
SD1: microSD-MOLEX-473521001; MOLEX_47352-1001
SW19: SW_x04; SW_DIP_SPSTx04_Slide_6.7x11.72mm_W6.73mm_P2.54mm_LowProfile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

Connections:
+3V3: SD1.4 (3V3); also elsewhere on the board
CS: SD1.2 (CS), SW19.5
GND: SD1.6 (GND); also elsewhere on the board
IO5: SW19.4; also elsewhere on the board
IO18: SW19.3; also elsewhere on the board
IO19: SW19.2; also elsewhere on the board
IO23: SW19.1; also elsewhere on the board
MISO: SD1.7 (MISO), SW19.7
MOSI: SD1.3 (MOSI), SW19.8
SCK: SD1.5 (SCK), SW19.6

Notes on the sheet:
microSD

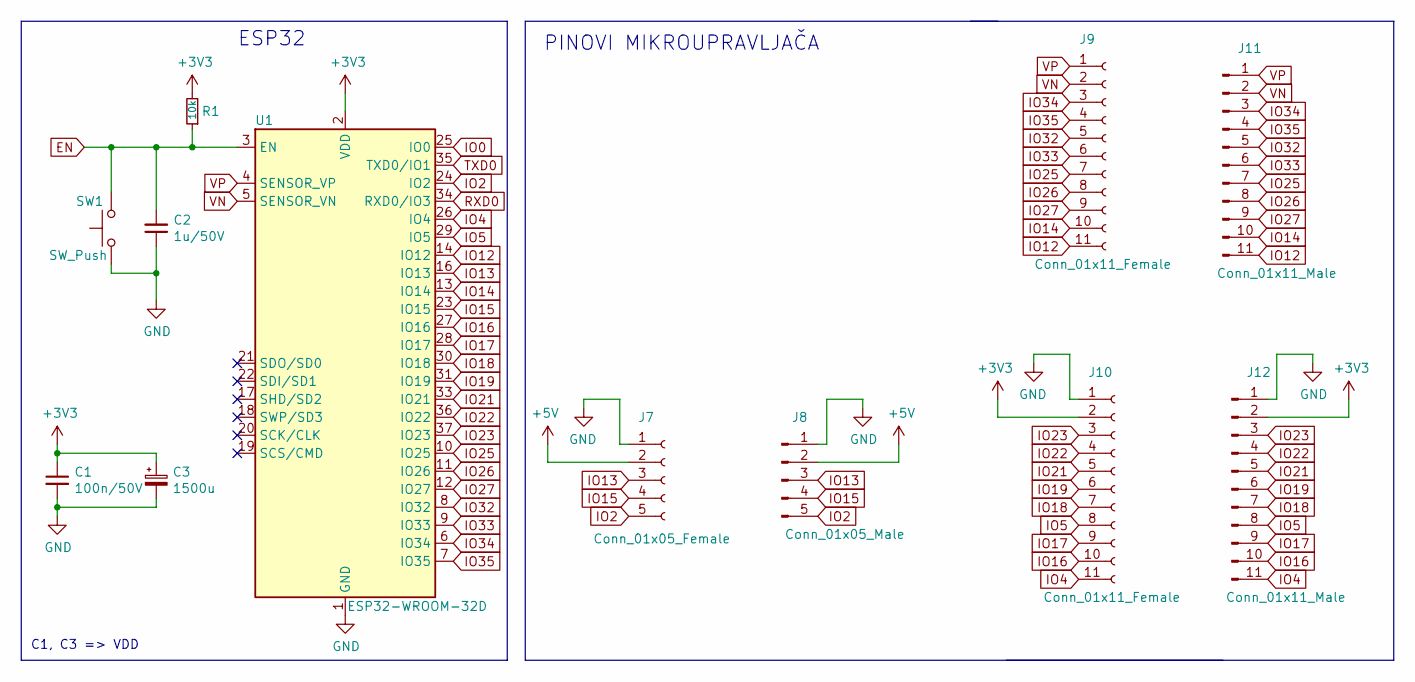
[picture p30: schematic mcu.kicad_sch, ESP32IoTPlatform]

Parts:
C1: 100n/50V; C_0805_2012Metric
C2: 1u/50V; C_0805_2012Metric
C3: 1500u; CP_EIA-7343-31_Kemet-D
J7: Conn_01x05_Female; PinSocket_1x05_P2.54mm_Vertical
J8: Conn_01x05_Male; PinHeader_1x05_P2.54mm_Vertical
J9, J10: Conn_01x11_Female; PinSocket_1x11_P2.54mm_Vertical
J11, J12: Conn_01x11_Male; PinHeader_1x11_P2.54mm_Vertical
R1: 10k; R_0805_2012Metric
SW1: SW_Push; SW_SPST_PTS645
U1: ESP32-WROOM-32D; ESP32-WROOM-32

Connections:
+3V3: C1.1, C3.1, J10.2, J12.2, R1.2, U1.2 (VDD); also elsewhere on the board
+5V: J7.2, J8.2; also elsewhere on the board
EN: C2.2, R1.1, SW1.2, U1.3 (EN); also elsewhere on the board
GND: C1.2, C2.1, C3.2, J7.1, J8.1, J10.1, J12.1, SW1.1, U1.1 (GND), U1.15 (GND), U1.38 (GND), U1.39 (GND); also elsewhere on the board
IO0: U1.25 (IO0); also elsewhere on the board
IO2: J7.5, J8.5, U1.24 (IO2); also elsewhere on the board
IO4: J10.11, J12.11, U1.26 (IO4); also elsewhere on the board
IO5: J10.8, J12.8, U1.29 (IO5); also elsewhere on the board
IO12: J9.11, J11.11, U1.14 (IO12)
IO13: J7.3, J8.3, U1.16 (IO13); also elsewhere on the board
IO14: J9.10, J11.10, U1.13 (IO14); also elsewhere on the board
IO15: J7.4, J8.4, U1.23 (IO15); also elsewhere on the board
IO16: J10.10, J12.10, U1.27 (IO16); also elsewhere on the board
IO17: J10.9, J12.9, U1.28 (IO17); also elsewhere on the board
IO18: J10.7, J12.7, U1.30 (IO18); also elsewhere on the board
IO19: J10.6, J12.6, U1.31 (IO19); also elsewhere on the board
IO21: J10.5, J12.5, U1.33 (IO21); also elsewhere on the board
IO22: J10.4, J12.4, U1.36 (IO22); also elsewhere on the board
IO23: J10.3, J12.3, U1.37 (IO23); also elsewhere on the board
IO25: J9.7, J11.7, U1.10 (IO25); also elsewhere on the board
IO26: J9.8, J11.8, U1.11 (IO26); also elsewhere on the board
IO27: J9.9, J11.9, U1.12 (IO27); also elsewhere on the board
IO32: J9.5, J11.5, U1.8 (IO32); also elsewhere on the board
IO33: J9.6, J11.6, U1.9 (IO33); also elsewhere on the board
IO34: J9.3, J11.3, U1.6 (IO34); also elsewhere on the board
IO35: J9.4, J11.4, U1.7 (IO35); also elsewhere on the board
RXD0: U1.34 (RXD0/IO3); also elsewhere on the board
TXD0: U1.35 (TXD0/IO1); also elsewhere on the board
VN: J9.2, J11.2, U1.5 (SENSOR_VN)
VP: J9.1, J11.1, U1.4 (SENSOR_VP)

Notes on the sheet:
ESP32
PINOVI MIKROUPRAVLJAČA
C1, C3 => VDD

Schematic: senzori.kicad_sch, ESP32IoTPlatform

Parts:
C19: 100n/50V; C_0805_2012Metric
C20: 10u/16V; C_0805_2012Metric
D13: Green; LED_0805_2012Metric
J5: Conn_01x04_Female; PinSocket_1x04_P2.54mm_Vertical
Q4: SI2302DS; SOT-23
R15: 1k; R_0805_2012Metric
R16: 1k5; R_0805_2012Metric
R17, R20: 10k; R_0805_2012Metric
R18: 470; R_0805_2012Metric
R19: LDR; R_LDR_7x6mm_P5.1mm_Vertical
R21: 243; R_0805_2012Metric
R22, R23, R24, R25, R26: 2k; R_0805_2012Metric
R31: 330; R_0805_2012Metric
RV1: 10k; Potentiometer_Bourns_3386P_Vertical
SW9: SW_x02; SW_DIP_SPSTx02_Slide_6.7x6.64mm_W6.73mm_P2.54mm_LowProfile_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
SW11: SW_x03; SW_DIP_SPSTx03_Slide_6.7x9.18mm_W6.73mm_P2.54mm_LowProfile_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
SW14, SW15, SW16: SW_x01; SW_DIP_SPSTx01_Slide_6.7x4.1mm_W6.73mm_P2.54mm_LowProfile_J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
SW17: SW_x05; SW_DIP_SPSTx05_Slide_6.7x14.26mm_W6.73mm_P2.54mm_LowProfile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
T1: SKRHABE010; Alps_SKRHABE010
TP1: Touchpad
U7: L80-M39

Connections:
+3V3: C19.1, C20.1, D13.2 (A), R19.1, R21.1, U7.4 (VCC), U7.5 (V_BCKP); also elsewhere on the board
+5V: J5.1; also elsewhere on the board
GND: C19.2, C20.2, J5.4, Q4.3 (S), R16.2, R17.2, R20.2, RV1.1, T1.5 (COMMON), U7.3 (GND), U7.12 (GND); also elsewhere on the board
IO2: SW17.3; also elsewhere on the board
IO4: SW16.1; also elsewhere on the board
IO5: SW11.1; also elsewhere on the board
IO15: SW17.4; also elsewhere on the board
IO16: SW11.3; also elsewhere on the board
IO17: SW11.2; also elsewhere on the board
IO18: SW17.2; also elsewhere on the board
IO23: SW17.1; also elsewhere on the board
IO25: SW17.5; also elsewhere on the board
IO27: SW9.2; also elsewhere on the board
IO33: SW9.1; also elsewhere on the board
IO34: SW15.1; also elsewhere on the board
IO35: SW14.1; also elsewhere on the board
unnamed: D13.1 (K), R18.2
unnamed: J5.2, SW9.3
unnamed: J5.3, R15.1
unnamed: Q4.1 (G), R17.1, R31.2
unnamed: Q4.2 (D), R18.1
unnamed: R15.2, R16.1, SW9.4
unnamed: R19.2, R20.1, SW14.2
unnamed: R21.2, RV1.3
unnamed: R22.1, T1.1 (A)
unnamed: R22.2, SW17.10
unnamed: R23.1, T1.2 (CENTER)
unnamed: R23.2, SW17.9
unnamed: R24.1, T1.3 (C)
unnamed: R24.2, SW17.8
unnamed: R25.1, T1.4 (B)
unnamed: R25.2, SW17.7
unnamed: R26.1, SW17.6
unnamed: R26.2, T1.6 (D)
unnamed: R31.1, U7.6 (1PPS)
unnamed: RV1.2, SW15.2
unnamed: SW11.4, U7.2 (TXD)
unnamed: SW11.5, U7.1 (RXD)
unnamed: SW11.6, U7.10 (~RESET)
unnamed: SW16.2, TP1.1

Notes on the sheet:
UPRAVLJAČKA RUČICA
FOTOOTPORNIK
UZ SENZOR UDALJENOSTI
GPS
POTENCIOMETAR
TOUCHPAD
C19, C20 => VCC

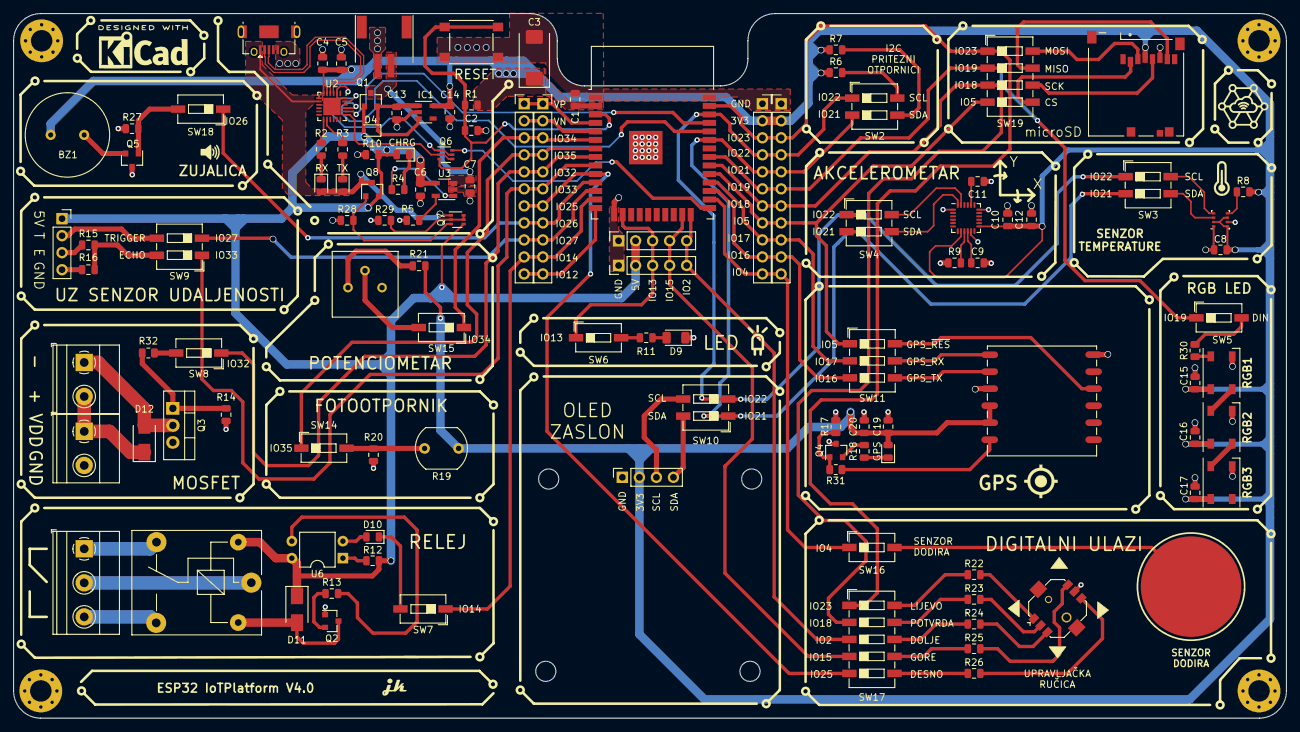
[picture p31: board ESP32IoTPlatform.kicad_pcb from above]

Board: 2 copper layers, 190.0 x 105.2 mm, 119 parts (0 on the bottom side), 107 nets.

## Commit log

2022-02-10 UZ model update
    [ESP32IoTPlatform.kicad_pcb]
2022-02-11 Schematic added
